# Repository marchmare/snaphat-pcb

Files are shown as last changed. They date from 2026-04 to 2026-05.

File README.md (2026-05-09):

# 🌻 SnapHAT - PCB design

<p align="center">
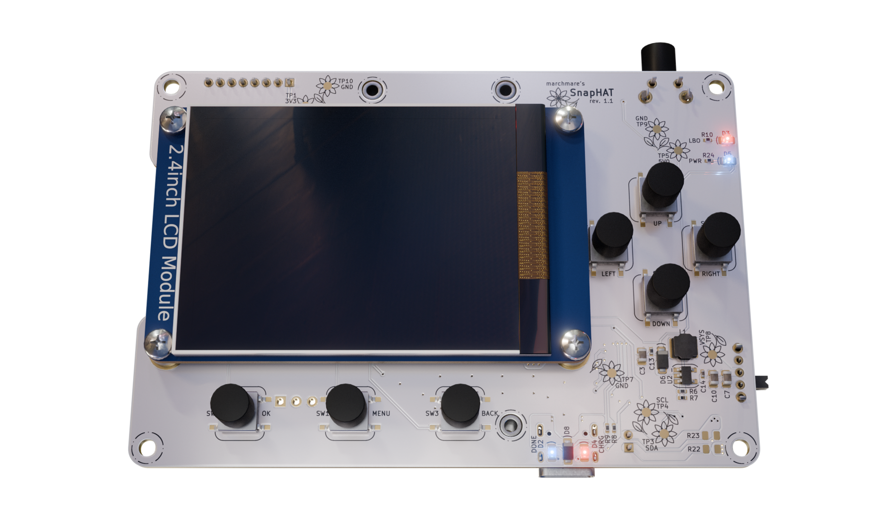
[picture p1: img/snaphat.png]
    
</p>

SnapHAT is an addon for RaspberryPi Zero 2 W serving as a handheld photo camera device.

This repository contains KiCad 9 design files for the PCBs of the SnapHAT device (rev.1.1).
The boards' layout is prepared to be compatible with JLCPCB standard 2-layer PCB quote.

> [!WARNING] 
> This repository is work in progress — core features are functional, but the PCB for this device is still evolving and some parts of the design are not yet behaving as I hoped.
> To avoid unnecessary hardware headaches, check [Troubleshooting and required reworks](#troubleshooting-and-required-reworks) section!

> [!TIP] 
> Python-based app for this camera can be found in **[this repository](https://github.com/marchmare/snaphat-sw)**.

### Table of contents:

* [Features](#features)
* [Repository structure](#repository-structure)
* [Bill of Materials](#bill-of-materials)
* [Wire harnesses](#wire-harnesses)
* [RaspberryPi header connection map](#raspberrypi-header-connection-map)
* [Troubleshooting and required reworks](#troubleshooting-and-required-reworks)

## Features

* 40-pin Raspberry Pi GPIO header for integration with RaspberryPi Zero 2 W
* 8-pin PH connector and mounting support for 320x240 Waveshare 18366 2.4" LCD TFT display
* Usable with ZeroCam OV5647 5MPx wide-angled 120° camera modules or same form-factor alternatives
* <del>1200mAh Li-Po battery support (30x40mm cell footprint, 2 pin PH connector), on-board battery charging (MCP73871) and power monitoring (INA219)</del>
* USB-C charging and OTG connector for RaspberryPi SD card access (USB 2.0)
* USB OTG pogo-pin breakout board as Raspberry Pi HAT, accessing USB singals through pogo-pins, connected to main board via 4pin FFC cable
* 8 tactile user interface buttons (navigation and shutter)
* LIS2DW12 motion sensor for providing image orientation metadata
* passive buzzer for audio feedback
* exposed debug UART pins
* flower testpads, because joy and whimsy is in demand

<p align="center">
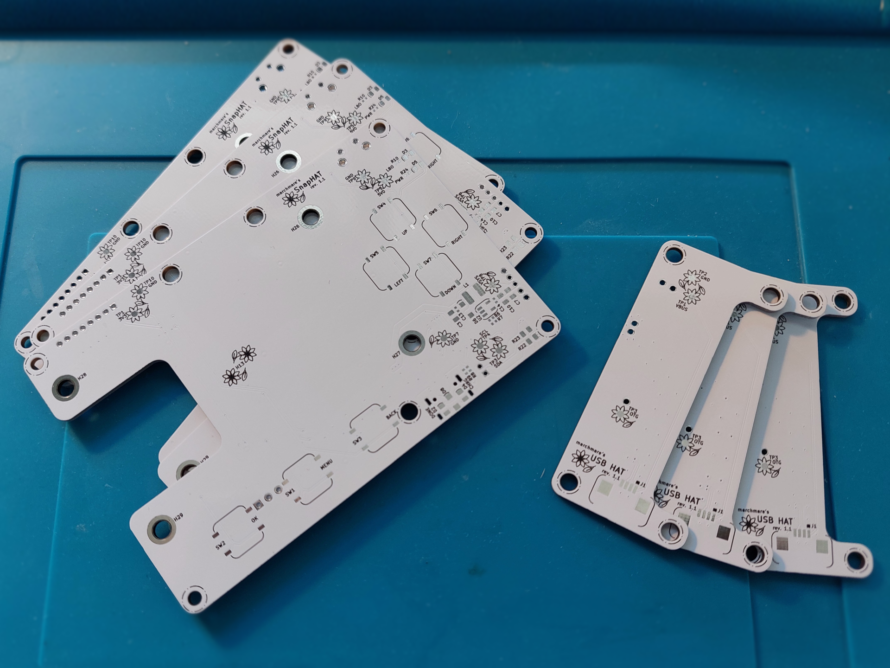
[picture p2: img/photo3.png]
    
</p>

## Repository structure

```
.
├─ main_board/
│   ├─ docs/
│   ├─ *.kicad_pro, *.kicad_sch, *.kicad_pcb
│   └─ README.md
├─ usb_hat/
│   ├─ docs/
│   ├─ *.kicad_pro, *.kicad_sch, *.kicad_pcb
│   └─ README.md
├─ img/
└─README.md
```

This repository contains two KiCad projects for each board:

* [**main_board**](main_board/) - SnapHAT main board with RaspberryPi socket connector and all camera device peripherals
* [**USB HAT**](usb_hat/) - USB OTG pogo-pin breakout board

Each board directory contains:

* `*.kicad_pro`, `*.kicad_sch`, `*.kicad_pcb` - KiCad 9 design files
* `docs/` - documentation outputs generated from the KiCad files - you will find BOM in CSV format and schematic PDF in there

In the root directory:
* `img/` - rendered previews of the boards and other images used by READMEs

## Bill of Materials

You can find BOMs for each board as CSV file in their respective `docs/` directories.
BOMs list PCB components, wire harness components, fasteners as well as OTS modules required to assemble the whole device. 

While designing SnapHAT, Farnell and TME were mostly taken into consideration as part vendors, however some parts need to be sourced from elsewhere (this applies mostly to OTS modules). 

Estimated component cost of the whole device is approximately 114 USD.

## Wire harnesses

<p align="center">
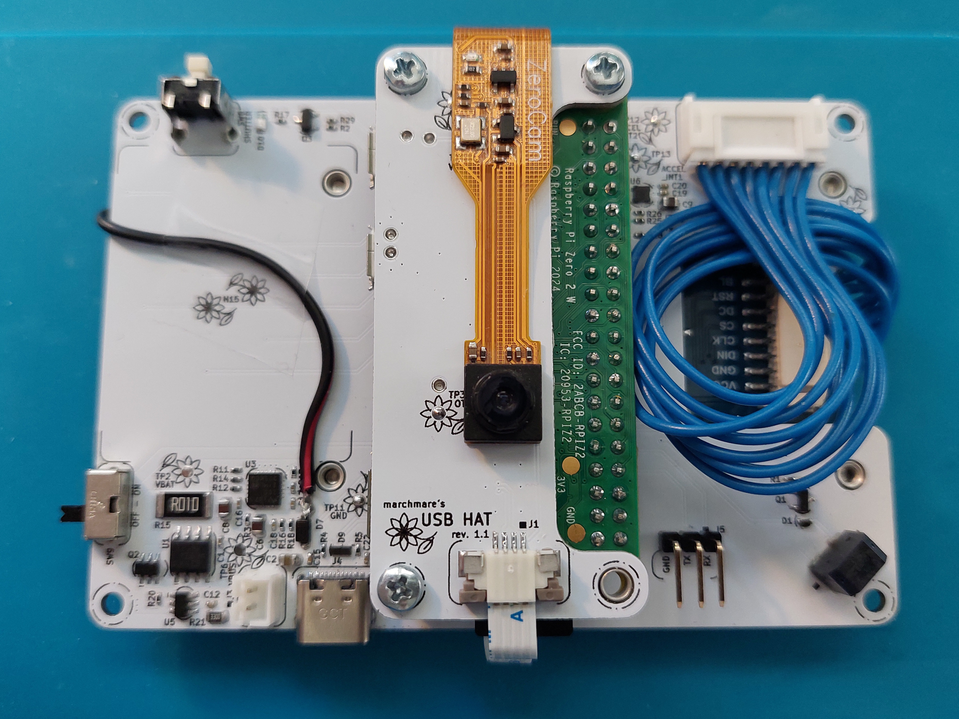
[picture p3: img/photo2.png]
    
</p>

### Display wire harness

To connect the Waveshare 18366 2.4" LCD TFT Display, use an 8-pin JST-PH (2.0 mm pitch) wire harness.
**This is not a straight-through cable — pin numbering is reversed between connectors.**

Part numbers for building the harness are listed in the main board's BOM and appear in its KiCad schematics as well.

#### Pin mapping:

| SnapHAT J1 | Signal | LCD PH connector |
|---|---|---|
| 1 | `3V3 (VCC)` | 8 |
| 2 | `GND` | 7 |
| 3 | `MOSI (DIN)`| 6 |
| 4 | `SCLK (CLK)`| 5 |
| 5 | `SPI_CS` | 4 |
| 6 | `DC` | 3 |
| 7 | `RST` | 2 |
| 8 | `BL` | 1 |

### USB HAT FFC cable

To connect SnapHAT's USB HAT, use 4 core (1.0 mm pitch) >50 mm FFC cable, with **opposite sided contacts**. Proposed part number for this cable is listed in the USB HAT's BOM and appear in its KiCad schematics as well.

SnapHAT and USB HAT both include FFC connectors with top-side contacts (SnapHAT: J6, USB HAT: J1). When plugged in, FFC stiffener should face the PCB on both ends.

#### Pin mapping:

| SnapHAT J6 | Signal | USB HAT J1 |
|---|---|---|
| 1 | `VBUS` | 1 |
| 2 | `USBC_DATA_N` | 2 |
| 3 | `USBC_DATA_P` | 3 |
| 4 | `GND` | 4 |

## RaspberryPi header connection map

Below table describes connected RaspberryPi GPIO pins and their intended function.

| Pin function | Signal name | GPIO (BCM) | Pin | Pin | GPIO (BCM) | Signal name | Pin function | 
| --- | --- | --- | --- | --- | --- | --- | --- |
| 3.3V power rail | `+3V3` | - | **1**  | **2**  | - | `+5V0` | 5V power rail |
| I2C data | `I2C_SDA` | 2 | **3**  | **4**  | - | `+5V0` | 5V power rail |
| I2C clock | `I2C_SCL` | 3 | **5**  | **6**  | - | `GND` | Ground |
| _Not connected_ | - | 4 | **7**  | **8**  | 14 | `RPI_UART_TX` | Debug UART Transmit |
| Ground | `GND` | - | **9**  | **10** | 15 | `RPI_UART_RX` | Debug UART Receive |
| Menu button | `BTN_MENU` | 17 | **11** | **12** | 18 | `BUZZER_SIGNAL`  | Buzzer PWM |
| A button | `BTN_A` | 27 | **13** | **14** | - | `GND` | Ground |
| B button | `BTN_B` | 22 | **15** | **16** | 23 | - | _Not connected_ |
| 3.3V power rail | `+3V3` | - | **17** | **18** | 24 | `DISPLAY_RST` | Display reset |
| Display SPI MOSI | `DISPLAY_MOSI` | 10 | **19** | **20** | - | `GND` | Ground |
| _Not connected_ | - | 9 | **21** | **22** | 25 | `DISPLAY_DC` | Display Data/Command |
| Display SPI serial clock  | `DISPLAY_SPI_SCLK` | 11 | **23** | **24** | 8 | `DISPLAY_SPI_CS` | Display SPI chip select |
| Ground | `GND` | - | **25** | **26** | 7 | - | _Not connected_ |
| Down button | `BTN_D` | 0 | **27** | **28** | 1 | - | _Not connected_ |
| Left button | `BTN_L` | 5 | **29** | **30** | - | `GND` | Ground |
| Right button | `BTN_R` | 6 | **31** | **32** | 12 | `DISPLAY_BL` | Display backlight PWM |
| Up button | `BTN_U` | 13 | **33** | **34** | - | `GND` | Ground |
| Low battery indicator LED | `LED_LBO` | 19 | **35** | **36** | 16 | `LED_SHUTTER` | Shutter activity LED indicator |
| Shutter button | `BTN_SHUTTER` | 26 | **37** | **38** | 20 | `ACCEL_INT1` | Motion sensor interrupt 1 |
| Ground | `GND` | - | **39** | **40** | 21 | `ACCEL_INT2` | Motion sensor interrupt 2 |

## Troubleshooting and required reworks

This revision's battery circuit (protection, charger and 5V boost) is still botched. Aside from this, SnapHAT is operational if powered by an external stable 5V supply like PC USB port or powerbank.

To make SnapHAT work in this case, simply connect VBUS to 5V0 (you can solder a wire between corresponding testpads). Keep the SW9 switch off to disable the battery charger circuit and prevent charging indicators flickering.

If you wish to dwell deeper into what's currently wrong with this design, here are symptoms observed during bringup:

* no power sourced from battery:
    - battery protection dual MOSFET have wrong topology, skip populating battery protection components entirely and populate R22 and R23 0R resistors instead to connect battery directly to the rest of the circuit. Make sure you use battery with a PCM in this case! 
* RaspberryPi stuck in boot loop when powering from battery or weaker USB port:
    - battery charging/boost regulator circuit is still wrong in this iteration, for the time being, connect VBUS testpad with the 5V0 one
* SnapHAT gets powered from connected USB-C connector when USB HAT is installed, despite turning SW9 in off position:
    - cut the VBUS trace going to J6 pin 1

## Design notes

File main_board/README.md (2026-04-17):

# SnapHAT main board

This directory contains design files and documentation for SnapHAT main board.

## Directory structure

```
.
└─ main_board/
   ├─ docs/
   │    ├─ *_bom.csv
   │    └─ *_schematic.pdf
   ├─ *.kicad_pro, *.kicad_sch, *.kicad_pcb
   └─ README.md
```

## Board previews

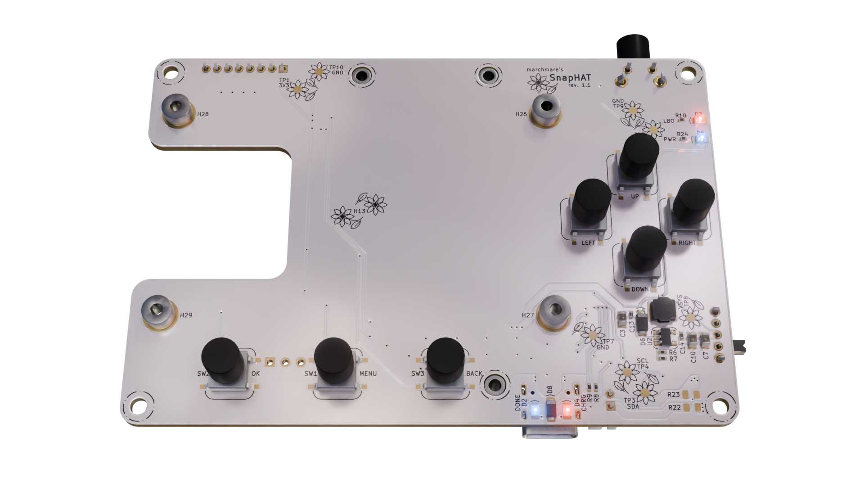
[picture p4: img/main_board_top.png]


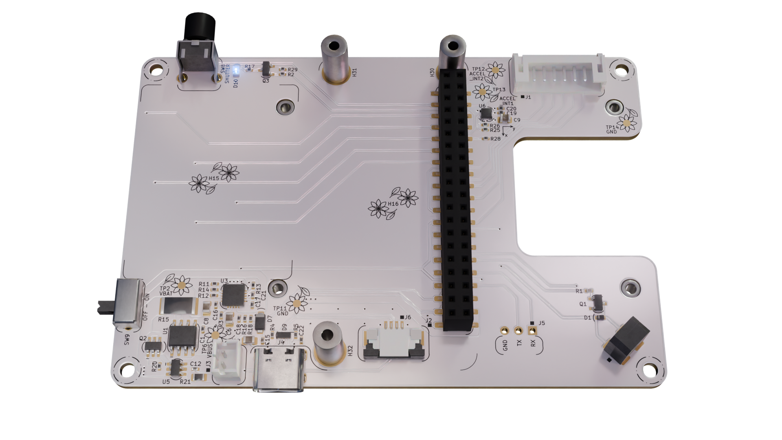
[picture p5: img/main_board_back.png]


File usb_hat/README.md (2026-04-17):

# SnapHAT USB HAT

This directory contains design files and documentation for SnapHAT USB HAT.

## Directory structure

```
.
└─ usb_hat/
   ├─ docs/
   │    ├─ *_bom.csv
   │    └─ *_schematic.pdf
   ├─ *.kicad_pro, *.kicad_sch, *.kicad_pcb
   └─ README.md
```

## Board previews

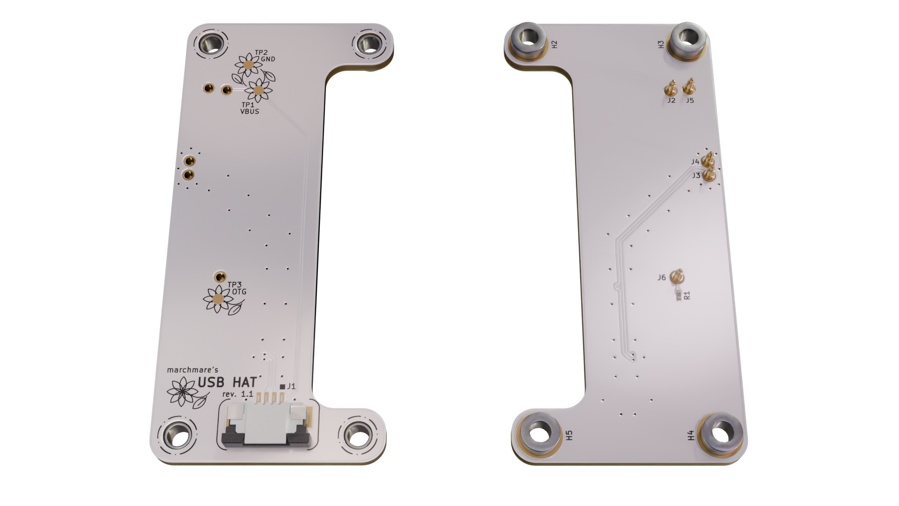
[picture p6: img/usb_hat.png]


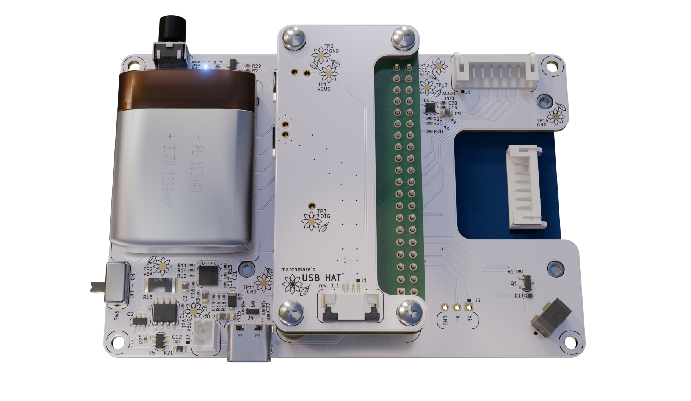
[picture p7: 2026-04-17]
img/snaphat_back.png

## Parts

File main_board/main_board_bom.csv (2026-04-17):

Reference | Qty | Value | Manufacturer | Part number | SKU | Category
BZ1 | 1 | KSSGL4B12-S | Kingstate | KSSGL4B12-S
C1,C12,C13,C14,C15,C16,C17,C18,C19,C20,C21,C22 | 12 | 100n | YAGEO | CS0402KRX7R7BB104
C2 | 1 | 22u | YAGEO | CC0805KKX5R5BB226
C3 | 1 | 2u2 | YAGEO | CC0805KKX7R6BB225
C6,C9,C10 | 3 | 10u | YAGEO | CC0805KFX7R6BB106
C7,C8 | 2 | 4u7 | YAGEO | CC0805KFX7R7BB475
D1 | 1 | 1N4148WT | ONSEMI | 1N4148WT
D2,D5,D10 | 3 | 0805 B LED | MULTICOMP PRO | MP008292
D3,D4 | 2 | 0805 R LED | MULTICOMP PRO | MP008293
D6,D7 | 2 | SL04-E3-08 | Vishay | SL04-E3-08
D8 | 1 | D_SMBJ5.0A | Littelfuse | SMBJ5.0A
D9 | 1 | SP1004U-ULC-04UTG | Littelfuse | SP1004U-ULC-04UTG
H1,H2,H3,H4,H5,H6,H7,H8 | 8 | B32-2010 | OMRON | B32-2010
H26,H27,H28,H29 | 4 | 9774030151R | Würth Elektronik | 9774030151R
H30,H31,H32 | 3 | 9774100151R | Würth Elektronik | 9774100151R
J1 | 1 | Conn_01x08_S8B-PH-K-S(LF)(SN) | JST | S8B-PH-K-S(LF)(SN)
J2 | 1 | Conn_02x20_2214SM-40G-75-PCR | MULTICOMP PRO | 2214SM-40G-75-PCR
J3 | 1 | Conn_01x02_B2B-PH-K-S(LF)(SN) | JST | B2B-PH-K-S(LF)(SN)
J4 | 1 | USB_C_USB4930-00-A | GCT | USB4930-00-A
J5 | 1 | Conn_01x03_MC34747 | MULTICOMP PRO | MC34747
J6 | 1 | Conn_01x04_FFC3B11-04-T | GCT | FFC3B11-04-T
L1 | 1 | L_LQH44PH100MPRL | Murata | LQH44PH100MPRL
Q1,Q3 | 2 | Q_BC817-25 | MULTICOMP PRO | BC817-25
Q2 | 1 | Q_FDC6561AN | ON Semiconductor | FDC6561AN
R1,R2,R12 | 3 | 1k | YAGEO | RC0402FR-071KL
R3,R11,R13,R16,R18,R25,R26 | 7 | 10k | YAGEO | RC0402FR-0710KL
R4,R5 | 2 | 5k1 | YAGEO | RC0402FR-075K1L
R6 | 1 | 100k | YAGEO | RC0402FR-07100KL
R7 | 1 | 33k | YAGEO | RC0402FR-0733KL
R8,R9,R17,R24 | 4 | 100R | YAGEO | RC0402JR-07100RL
R10 | 1 | 47R | YAGEO | RC0402JR-0747RL
R14,R20 | 2 | 2k7 | YAGEO | RC0402FR-072K7L
R15 | 1 | 0R01 | YAGEO | RL2512FK-070R01L
R21 | 1 | 330R | YAGEO | RC0805FR-07330RL
R22,R23 | 2 | 0R | YAGEO | RC0805JR-070RL
R28,R29 | 2 | 330R | YAGEO | RC0402FR-07330RL
SW1,SW2,SW3,SW4,SW5,SW6,SW7 | 7 | SW_B3FS-1050 | OMRON | B3FS-1050
SW8 | 1 | SW_B3F-3150 | OMRON | B3F-3150
SW9 | 1 | 1825232-1 | TE Connectivity | 1825232-1
U1 | 1 | INA219BIDR | Texas Instruments | INA219BIDR
U2 | 1 | MIC2250-1YD5-TR | Microchip Technology | MIC2250-1YD5-TR
U3 | 1 | MCP73871T-2CCI/ML | Microchip Technology | MCP73871T-2CCI/ML
U5 | 1 | AP9101CAK6-ABTRG1 | Diodes Inc. | AP9101CAK6-ABTRG1
U6 | 1 | LIS2DW12TR | STMicroelectronics | LIS2DW12TR
H9,H10,H11,H12 | 4 | 1386735 | BOSSARD | 1386735 |  | Fasteners
H34,H35,H36,H37 | 4 | M2.5x4 | BOSSARD | 1250396 |  | Fasteners
H40,H41,H42,H43 | 4 | M2.5x8 | BOSSARD | 1250434 |  | Fasteners
H44,H45,H46,H47 | 4 | M2.5x12 | BOSSARD | 1538543 |  | Fasteners
H53 | 1 | M2.5 nut | BOSSARD | 1088254 |  | Fasteners
H13 | 1 | 18366 | Waveshare | 18366 |  | OTS
H14 | 1 | ODS105 | Odseven | ODS105 |  | OTS
H15 | 1 | 10304 |  | 10304 |  | OTS
H16 | 1 | Raspberry Pi Zero 2 W | Raspberry Pi | SC1176 |  | OTS
H17,H18 | 2 | PHR-8 | JST | PHR-8 |  | Wire harness
H19,H20,H21,H22,H23,H24,H25,H52 | 8 | 01SPHSPH-26L-150 | JST | 01SPHSPH-26L-150 |  | Wire harness
H48,H49 | 2 | SPH-002T-P0.5S | JST | SPH-002T-P0.5S |  | Wire harness
H50 | 1 | PHR-2 | JST | PHR-2 |  | Wire harness

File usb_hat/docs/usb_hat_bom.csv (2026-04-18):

Reference | Qty | Value | Manufacturer | Part number | SKU | Category
H2,H3,H4,H5 | 4 | 9774020951R | Würth Elektronik | 9774020951R
J1 | 1 | Conn_01x04_FFC3B11-04-T | GCT | FFC3B11-04-T
J2,J3,J4,J5,J6 | 5 | P70-6000045R | Harwin | P70-6000045R
R1 | 1 | 0R | YAGEO | RC0402JR-070RL
H1 | 1 | 10-04-D-0050-C-4-08-4-T | GCT | 10-04-D-0050-C-4-08-4-T |  | Wire harness

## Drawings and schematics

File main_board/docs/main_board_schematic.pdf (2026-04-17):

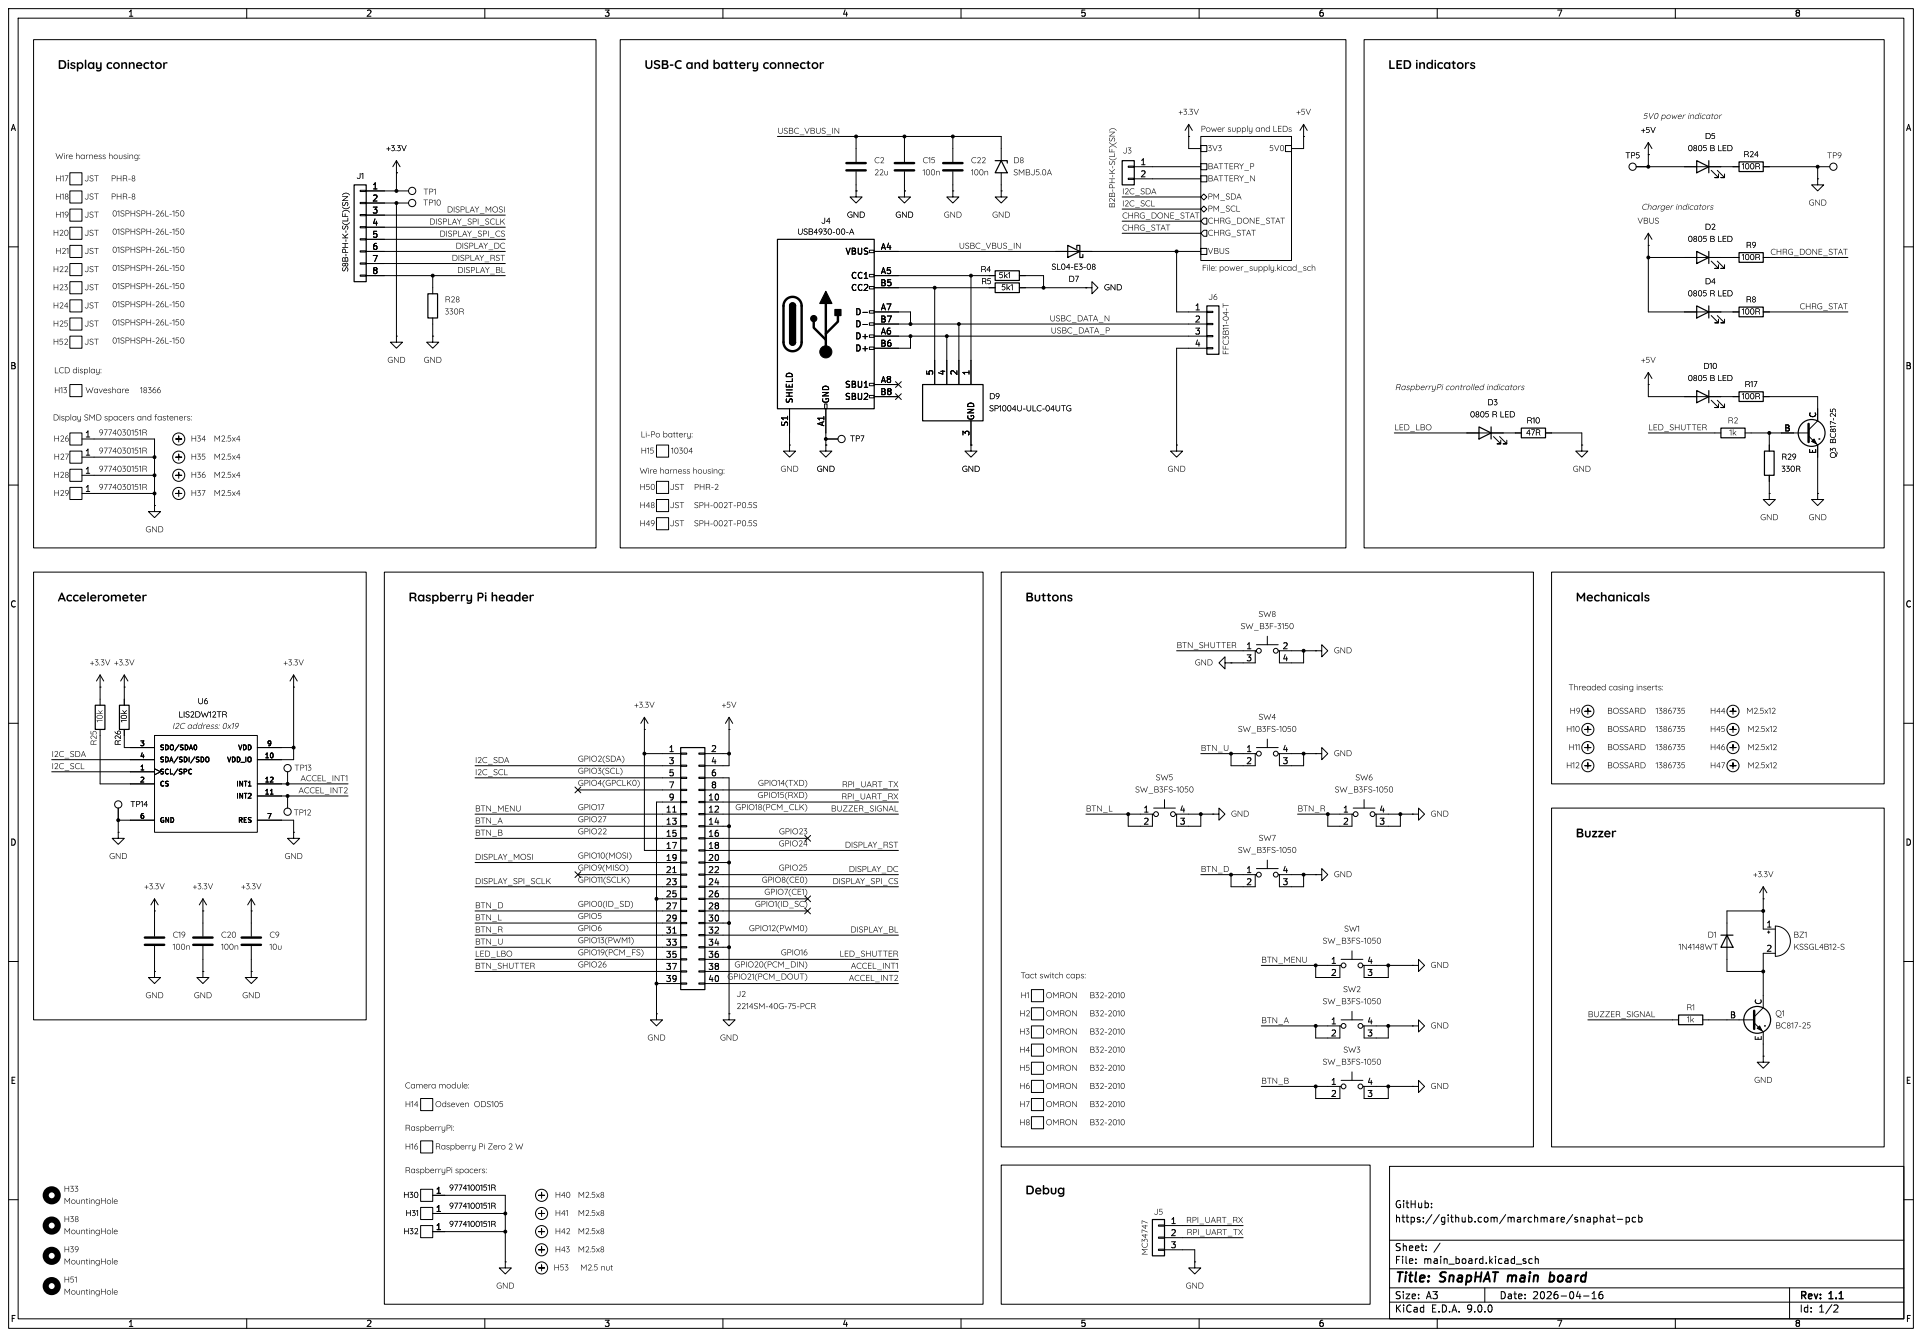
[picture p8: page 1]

Wire harness housing: LCD display:

USB-Cand battery connector

5V0 power indicator Charger indicators Buttons Wire harness housing: Li-Po battery:

VBUS CHRG_DONE_STAT CHRG_STAT Power supply and LEDs File:power_supply.kicad_sch

File: main_board.kicad_sch Sheet: / https://github.com/marchmare/snaphat-pcb GitHub:

Id: 1/2 Title: SnapHAT main board

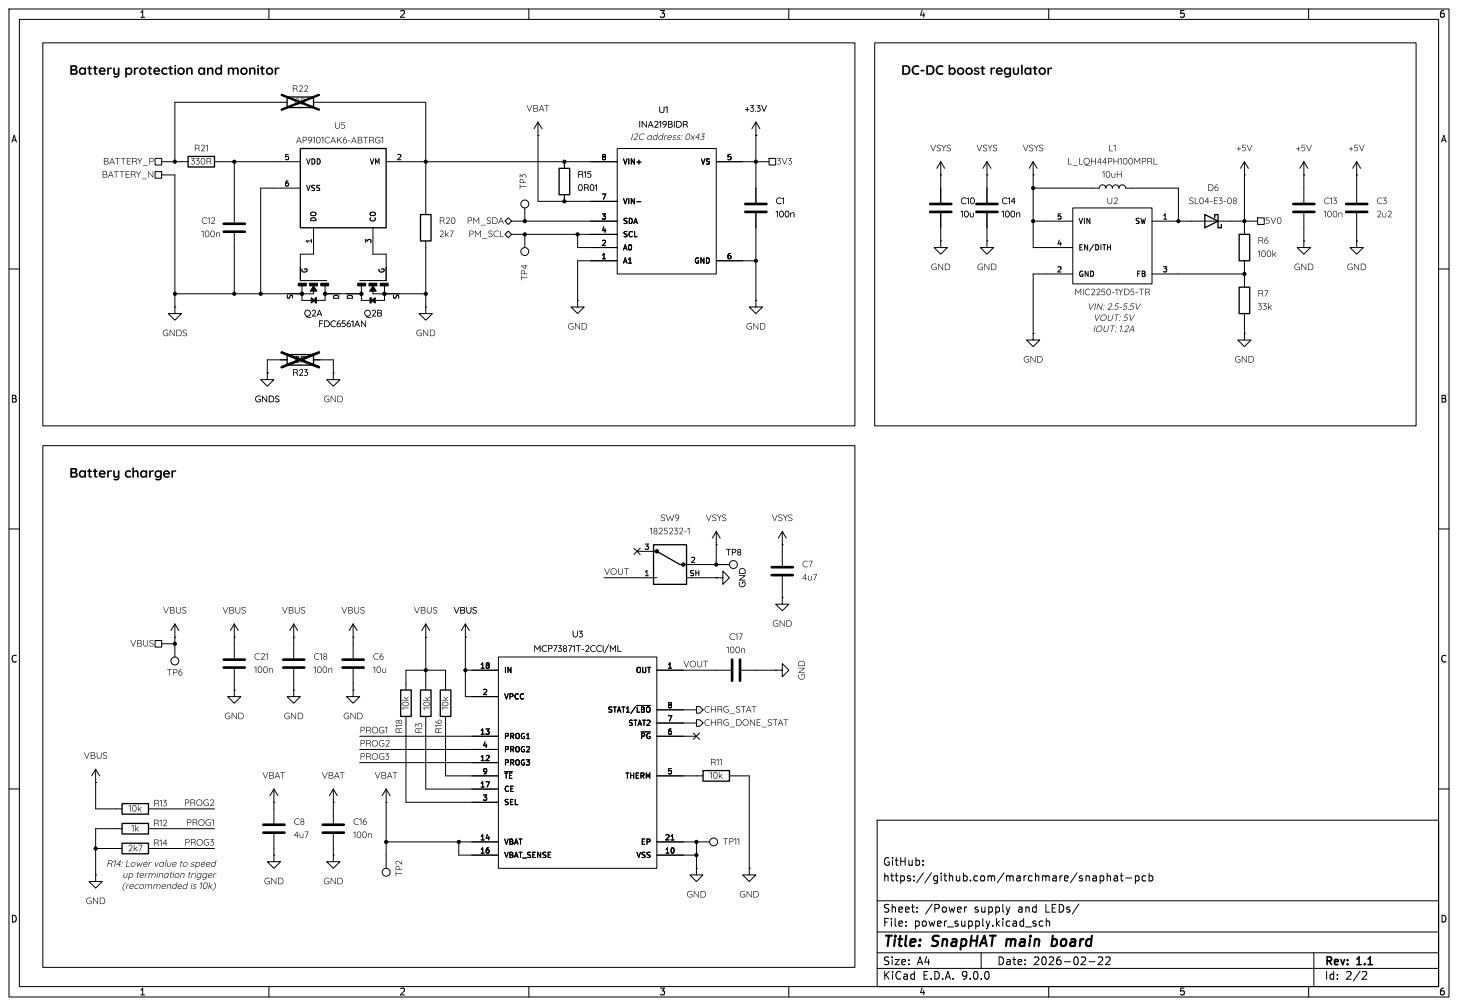
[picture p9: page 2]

IOUT:1.2A DC-DC boost regulator

R14:Lower value to speed
up termination trigger
(recommended is 10k)

Id: 2/2 Title: SnapHAT main board

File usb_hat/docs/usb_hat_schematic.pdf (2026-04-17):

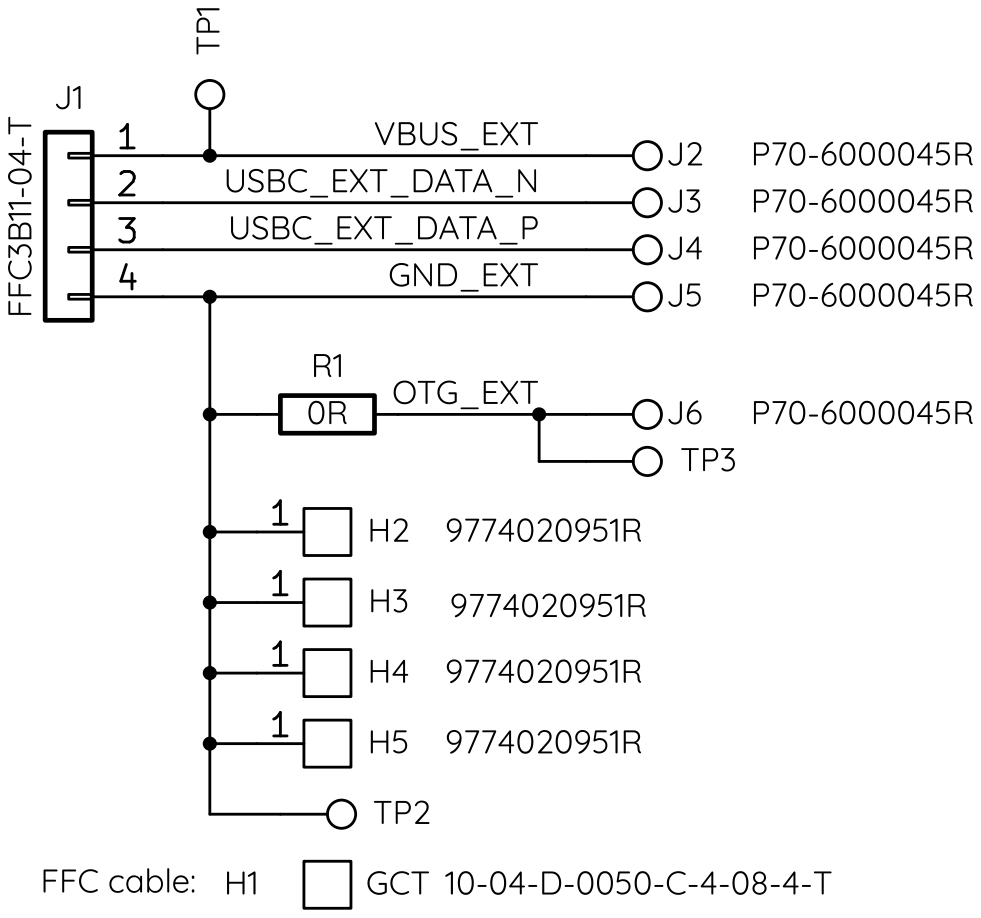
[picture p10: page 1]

File: usb_hat.kicad_sch Sheet: / https://github.com/marchmare/snaphat-pcb GitHub:

Id: 1/1 Title: USB HAT

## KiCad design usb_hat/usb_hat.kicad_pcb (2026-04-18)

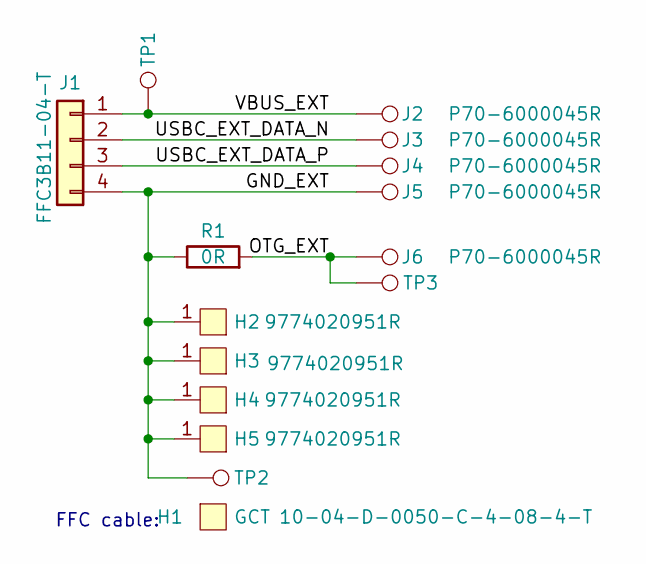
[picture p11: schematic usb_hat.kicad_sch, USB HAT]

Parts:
H1: 10-04-D-0050-C-4-08-4-T; Part number 10-04-D-0050-C-4-08-4-T
H2, H3, H4, H5: 9774020951R; Mounting_Wuerth_WA-SMST-2.7mm_H2mm_9774020951; Part number 9774020951R
J1: Conn_01x04_FFC3B11-04-T; GCT_FFC3B11-04-T; Part number FFC3B11-04-T
J2, J3, J4, J5, J6: P70-6000045R; HARWIN_P70-6000045R; Part number P70-6000045R
R1: 0R; R_0402_1005Metric; Part number RC0402JR-070RL
TP1, TP2, TP3: TestPoint; TestPoint_Pad_D1.5mm

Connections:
/GND_EXT: H2.1, H3.1, H4.1, H5.1, J1.4, J5.1, R1.1, TP2.1
/OTG_EXT: J6.1, R1.2, TP3.1
/USBC_EXT_DATA_N: J1.2, J3.1
/USBC_EXT_DATA_P: J1.3, J4.1
/VBUS_EXT: J1.1, J2.1, TP1.1

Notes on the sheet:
FFC cable:

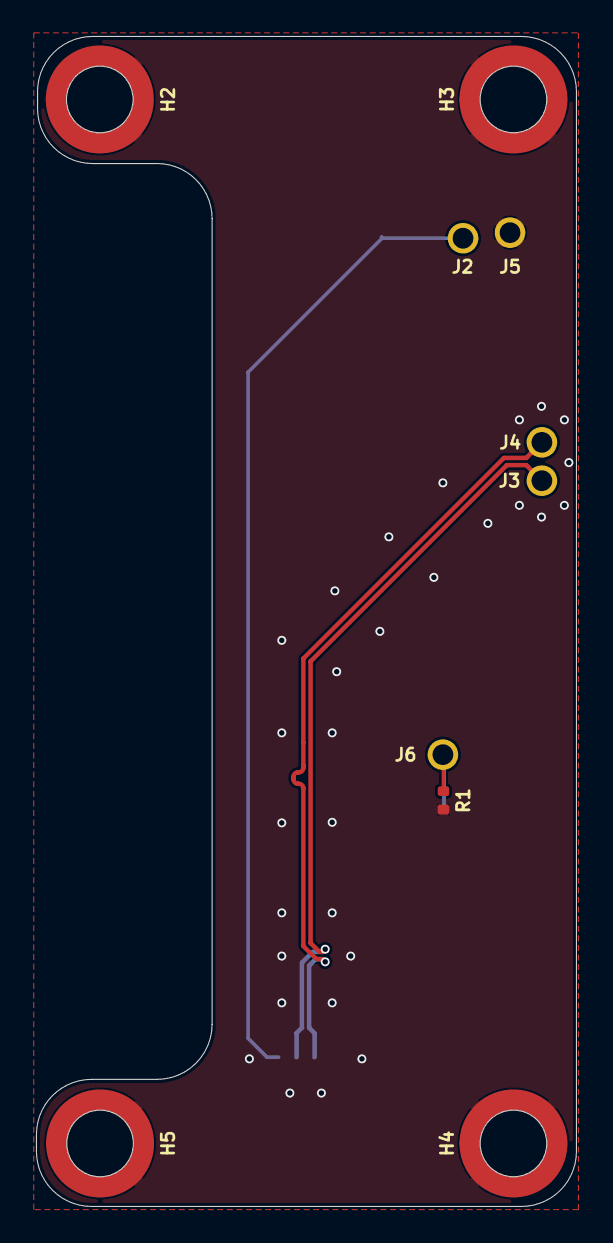
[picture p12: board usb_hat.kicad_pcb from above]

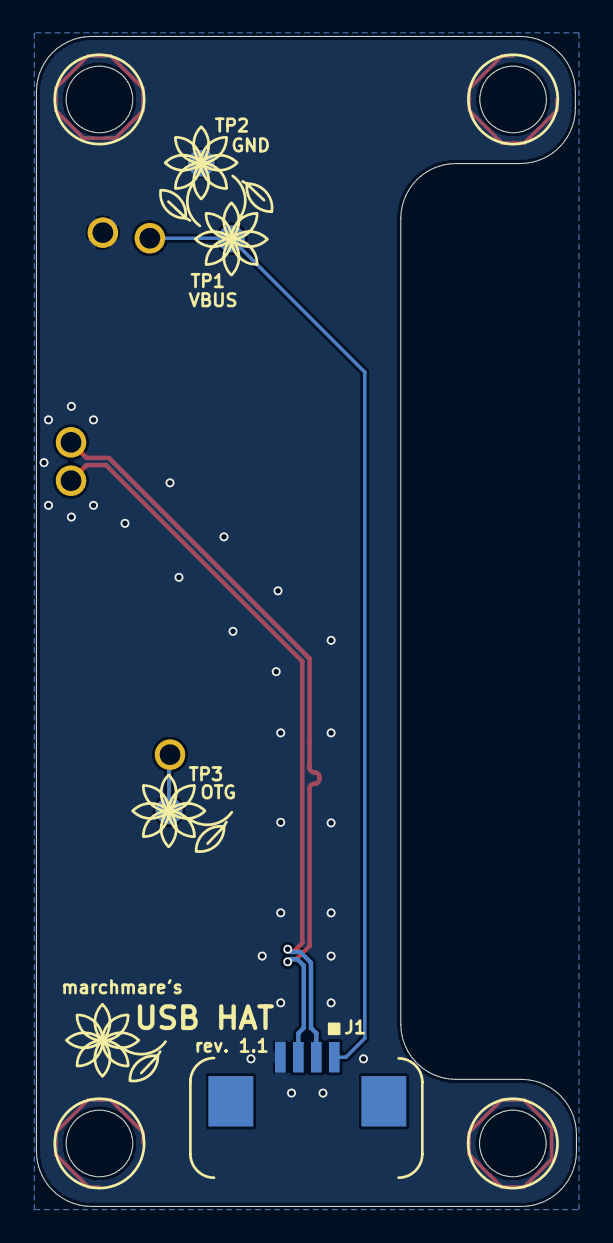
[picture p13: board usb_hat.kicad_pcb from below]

Board: 2 copper layers, 30.0 x 65.0 mm, 14 parts (4 on the bottom side), 5 nets.

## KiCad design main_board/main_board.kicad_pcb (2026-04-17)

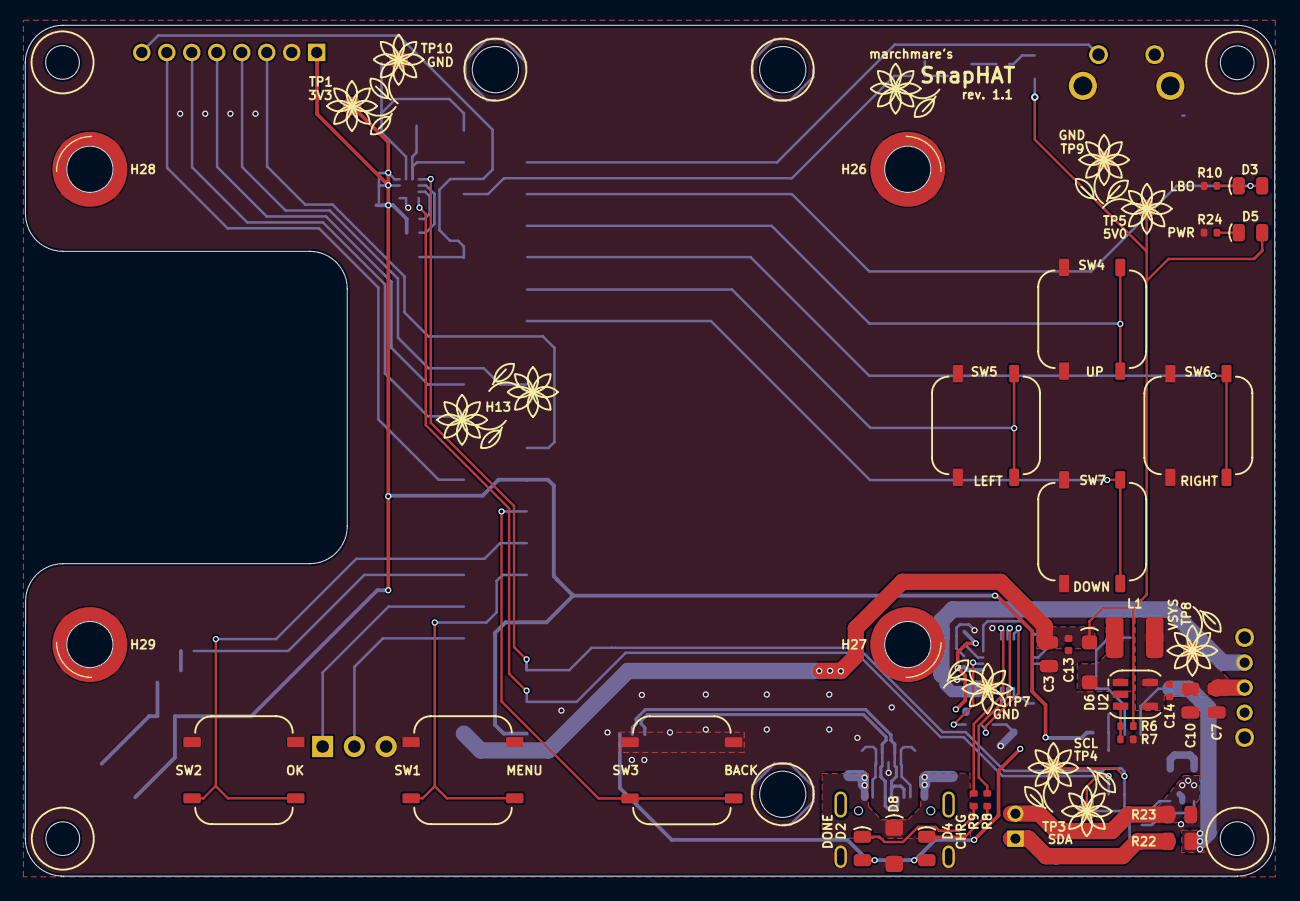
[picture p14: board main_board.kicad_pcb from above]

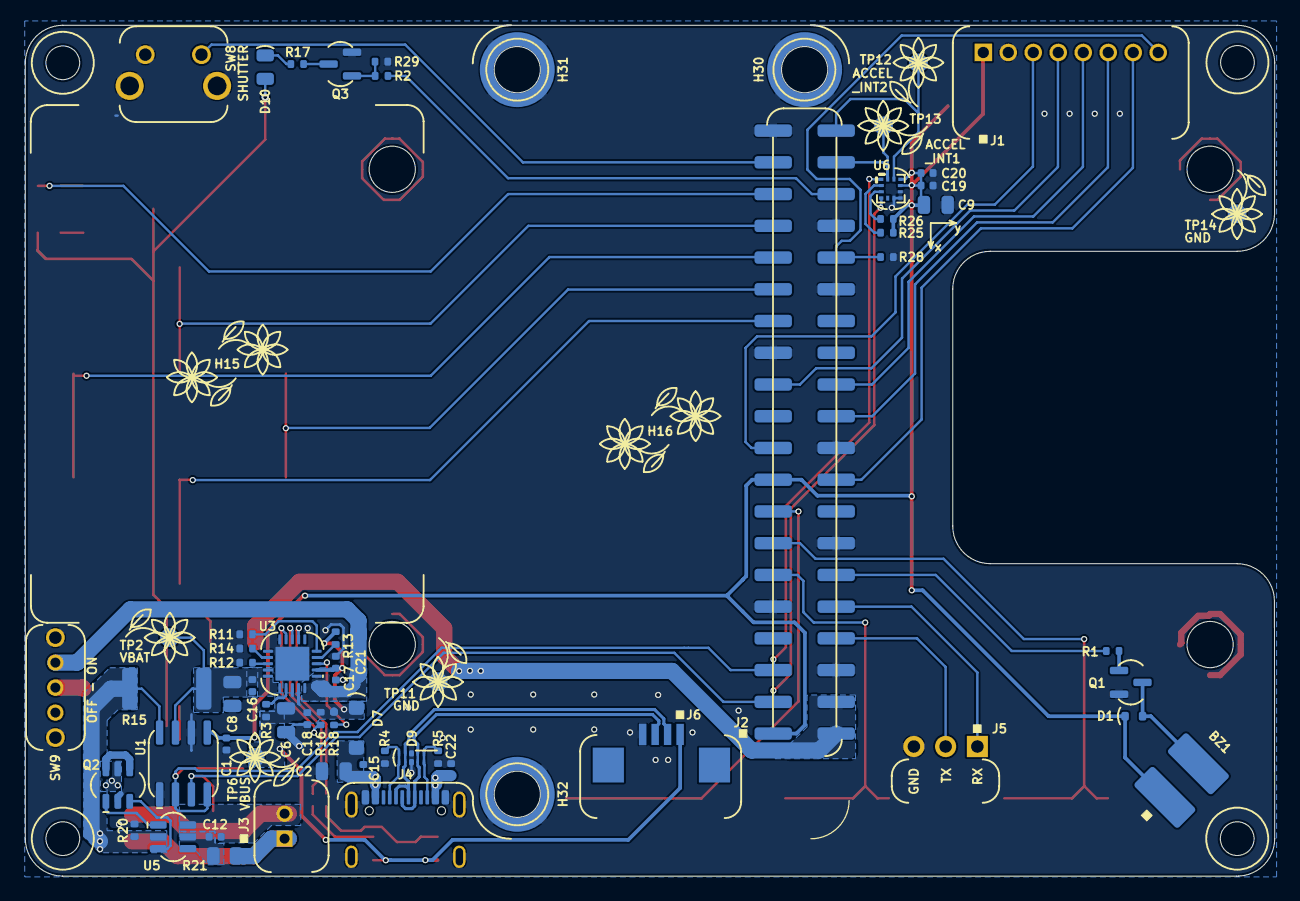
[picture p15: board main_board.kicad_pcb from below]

Board: 2 copper layers, 100.0 x 68.1 mm, 109 parts (64 on the bottom side), 64 nets.

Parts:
BZ1: KSSGL4B12-S; XDCR_KSSGL4B12-S
C1, C12, C13, C14, C15, C16, C17, C18, C19, C20, C21, C22: 100n; C_0402_1005Metric
C2: 22u; C_0805_2012Metric
C3: 2u2; C_0805_2012Metric
C6, C9, C10: 10u; C_0805_2012Metric
C7, C8: 4u7; C_0805_2012Metric
D1: 1N4148WT; D_SOD-523
D2, D5, D10: 0805 B LED; LED_0805_2012Metric
D3, D4: 0805 R LED; LED_0805_2012Metric
D6, D7: SL04-E3-08; DO-219AB
D8: D_SMBJ5.0A; SOD-123FL
D9: SP1004U-ULC-04UTG; SP1004UULC04UTG
H13: 18366
H15: 10304; Li-Pol_battery_8x30x40mm
H16: Raspberry Pi Zero 2 W; Raspberry_Pi_Zero_Socketed_THT_FaceDown_MountingHoles
H26, H27, H28, H29: 9774030151R; Mounting_Wuerth_WA-SMSI-M2.5_H3mm_9774030151R
H30, H31, H32: 9774100151R; Mounting_Wuerth_WA-SMSI-M2.5_H10mm_9774100151R
H33, H38, H39, H51: MountingHole; MountingHole_2.7mm
J1: Conn_01x08_S8B-PH-K-S(LF)(SN); JST_S8B-PH-K-S_LF__SN_
J2: Conn_02x20_2214SM-40G-75-PCR; PinSocket_2x20_P2.54mm_Vertical_SMD
J3: Conn_01x02_B2B-PH-K-S(LF)(SN); JST_B2B-PH-K-S_LF__SN_
J4: USB_C_USB4930-00-A; USB_C_Receptacle_GCT_USB4105-xx-A_16P_TopMnt_Horizontal
J5: Conn_01x03_MC34747; PinHeader_1x03_P2.54mm_Horizontal
J6: Conn_01x04_FFC3B11-04-T; GCT_FFC3B11-04-T
L1: L_LQH44PH100MPRL; L_LPH44PH
Q1, Q3: Q_BC817-25; SOT-23
Q2: Q_FDC6561AN; SSOT-6
R1, R2, R12: 1k; R_0402_1005Metric
R3, R11, R13, R16, R18, R25, R26: 10k; R_0402_1005Metric
R4, R5: 5k1; R_0402_1005Metric
R6: 100k; R_0402_1005Metric
R7: 33k; R_0402_1005Metric
R8, R9, R17, R24: 100R; R_0402_1005Metric
R10: 47R; R_0402_1005Metric
R14, R20: 2k7; R_0402_1005Metric
R15: 0R01; R_2512_6332Metric
R21: 330R; R_0805_2012Metric
R22, R23: 0R; R_0805_2012Metric
R28, R29: 330R; R_0402_1005Metric
SW1, SW2, SW3, SW4, SW5, SW6, SW7: SW_B3FS-1050; SW_B3FS-105xx
SW8: SW_B3F-3150
SW9: 1825232-1
TP1, TP2, TP3, TP4, TP5, TP6, TP7, TP8, TP9, TP10, TP11, TP12, TP13, TP14: TestPoint; TestPoint_Pad_D1.5mm
U1: INA219BIDR; SOIC-8_3.9x4.9mm_P1.27mm
U2: MIC2250-1YD5-TR; TSOT-23-5
U3: MCP73871T-2CCI/ML; QFN-20-1EP_4x4mm_P0.5mm_EP2.7x2.7mm
U5: AP9101CAK6-ABTRG1; SOT-26
U6: LIS2DW12TR; LGA12R50P4X4_200X200X70

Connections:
+3.3V: BZ1.1 (+), C1.1, C9.1, C19.1, C20.1, D1.1 (K), J1.1, J2.1, J2.17, R25.2, R26.2, TP1.1, U1.5 (VS), U6.9 (VDD), U6.10 (VDD_IO)
+5V: C3.1, C13.2, D5.2 (A), D6.1 (K), D10.2 (A), J2.2, J2.4, R6.1, TP5.1
/ACCEL_INT1: J2.38, TP13.1, U6.12 (INT1)
/ACCEL_INT2: J2.40, TP12.1, U6.11 (INT2)
/BTN_A: J2.13, SW2.1, SW2.2
/BTN_B: J2.15, SW3.1, SW3.2
/BTN_D: J2.27, SW7.1, SW7.2
/BTN_L: J2.29, SW5.1, SW5.2
/BTN_MENU: J2.11, SW1.1, SW1.2
/BTN_R: J2.31, SW6.1, SW6.2
/BTN_SHUTTER: J2.37, SW8.1
/BTN_U: J2.33, SW4.1, SW4.2
/BUZZER_SIGNAL: J2.12, R1.1
/CHRG_DONE_STAT: R9.1, U3.7 (STAT2)
/CHRG_STAT: R8.1, U3.8 (STAT1/~LBO)
/DISPLAY_BL: J1.8, J2.32, R28.1
/DISPLAY_DC: J1.6, J2.22
/DISPLAY_MOSI: J1.3, J2.19
/DISPLAY_RST: J1.7, J2.18
/DISPLAY_SPI_CS: J1.5, J2.24
/DISPLAY_SPI_SCLK: J1.4, J2.23
/I2C_SCL: J2.5, TP4.1, U1.2 (A0), U1.4 (SCL), U6.1 (SCL/SPC)
/I2C_SDA: J2.3, TP3.1, U1.3 (SDA), U6.4 (SDA/SDI/SDO)
/LED_LBO: D3.2 (A), J2.35
/LED_SHUTTER: J2.36, R2.1
/Power supply and LEDs/BATTERY_P: J3.1, R21.2, R22.1
/Power supply and LEDs/PROG1: R12.1, U3.13 (PROG1)
/Power supply and LEDs/PROG2: R13.1, U3.4 (PROG2)
/Power supply and LEDs/PROG3: R14.2, U3.12 (PROG3)
/Power supply and LEDs/VOUT: C17.2, SW9.1, U3.1 (OUT), U3.20 (OUT)
/RPI_UART_RX: J2.10, J5.1
/RPI_UART_TX: J2.8, J5.2
/USBC_DATA_N: D9.2, D9.9 (NC_3), J4.A7 (D-), J4.B7 (D-), J6.2
/USBC_DATA_P: D9.4, D9.7 (NC_2), J4.A6 (D+), J4.B6 (D+), J6.3
/USBC_VBUS_IN: C2.1, C15.2, C22.2, D7.2 (A), D8.1 (A1), J4.A4 (VBUS), J4.A9 (VBUS), J4.B4 (VBUS), J4.B9 (VBUS)
GND: C1.2, C2.2, C3.2, C6.2, C7.2, C8.2, C9.2, C10.2, C13.1, C14.1, C15.1, C16.1, C17.1, C18.1, C19.2, C20.2, C21.1, C22.1, D8.2 (A2), D9.3 (GND), D9.8 (GND_2), H26.1, H27.1, H28.1, H29.1, H30.1, H31.1, H32.1, J1.2, J2.6, J2.9, J2.14, J2.20, J2.25, J2.30, J2.34, J2.39, J4.A1 (GND), J4.A12 (GND), J4.B1 (GND), J4.B12 (GND), J4.S1 (SHIELD), J5.3, J6.4, Q1.2 (E), Q2.2, Q3.2 (E), R4.1, R5.1, R7.2, R10.1, R11.1, R12.2, R14.1, R20.1, R23.2, R24.1, R28.2, R29.2, SW1.3 (K), SW1.4 (A), SW2.3 (K), SW2.4 (A), SW3.3 (K), SW3.4 (A), SW4.3 (K), SW4.4 (A), SW5.3 (K), SW5.4 (A), SW6.3 (K), SW6.4 (A), SW7.3 (K), SW7.4 (A), SW8.2, SW8.3, SW8.4, SW9.SH, TP7.1, TP9.1, TP10.1, TP11.1, TP14.1, U1.1 (A1), U1.6 (GND), U2.2 (GND), U3.10 (VSS), U3.11 (VSS), U3.21 (EP), U6.6 (GND), U6.7 (RES), U6.8 (GND)
GNDS: C12.2, J3.2, Q2.5, R23.1, U5.6 (VSS)
unnamed: BZ1.2 (-), D1.2 (A), Q1.3 (C)
unnamed: D2.1 (K), R9.2
unnamed: D3.1 (K), R10.2
unnamed: D4.1 (K), R8.2
unnamed: D5.1 (K), R24.2
unnamed: D6.2 (A), L1.2, U2.1 (SW)
unnamed: D9.5, D9.6 (NC_1), J4.B5 (CC2), R5.2
unnamed: D9.1, D9.10 (NC_4), J4.A5 (CC1), R4.2
unnamed: D10.1 (K), R17.1
unnamed: Q1.1 (B), R1.2
unnamed: Q2.4, Q2.6
unnamed: Q3.1 (B), R2.2, R29.1
unnamed: Q3.3 (C), R17.2
unnamed: R15.1, R20.2, R22.2, U1.8 (VIN+), U5.2 (VM)
unnamed: R6.2, R7.1, U2.3 (FB)
unnamed: R3.2, U3.17 (CE)
unnamed: R18.2, U3.3 (SEL)
unnamed: R11.2, U3.5 (THERM)
unnamed: R16.1, U3.9 (~TE)
unnamed: Q2.3, U5.3 (CO)
unnamed: Q2.1, U5.1 (DO)
unnamed: C12.1, R21.1, U5.5 (VDD)
unnamed: R25.1, U6.2 (CS)
unnamed: R26.1, U6.3 (SDO/SDA0)
VBAT: C8.1, C16.2, R15.2, TP2.1, U1.7 (VIN-), U3.14 (VBAT), U3.15 (VBAT), U3.16 (VBAT_SENSE)
VBUS: C6.1, C18.2, C21.2, D2.2 (A), D4.2 (A), D7.1 (K), J6.1, R3.1, R13.2, R16.2, R18.1, TP6.1, U3.2 (VPCC), U3.18 (IN), U3.19 (IN)
VSYS: C7.1, C10.1, C14.2, L1.1, SW9.2, TP8.1, U2.4 (EN/DITH), U2.5 (VIN)

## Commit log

2026-03-19 Add design files, README, bom and schematic
    [snaphat.kicad_pcb, snaphat.kicad_sch, snaphat_bom.csv]
2026-03-19 Replace boost regulator with MIC2250-1YD5-TR
    [snaphat.kicad_sch]
2026-03-19 Add display backlight pulldown
    [snaphat.kicad_sch]
2026-03-19 Update slide switch reference to SW
    [snaphat.kicad_sch]
2026-03-19 Replace Q2 and Q3 with FDC6561AN
    [snaphat.kicad_sch]
2026-03-20 Add USB OTG
    [snaphat.kicad_sch]
2026-03-22 Move power supply block to separate sheet, bringup fixes
    [power_supply.kicad_sch, snaphat.kicad_sch]
2026-03-22 Fix BC817-25 symbol (wrong pinout)
    [snaphat.kicad_sch]
2026-03-22 Update spacers
    [snaphat.kicad_sch]
2026-03-22 Fix B3F-3150 symbol
    [snaphat.kicad_sch]
2026-03-22 Fixes to power charger, cleanup schematic
    [power_supply.kicad_sch, snaphat.kicad_sch]
2026-04-09 Start updating PCB, library fixes
    [power_supply.kicad_sch, snaphat.kicad_pcb, snaphat.kicad_sch]
2026-04-10 Rerouted power and USB
    [snaphat.kicad_pcb, snaphat.kicad_sch]
2026-04-11 Fix RPi connector on schematic, route rest of signals
    [snaphat.kicad_pcb, snaphat.kicad_sch]
2026-04-11 Layout nits, add proper mounting holes
    [snaphat.kicad_pcb, snaphat.kicad_sch]
2026-04-11 Zone fixes
    [snaphat.kicad_pcb]
2026-04-11 Fix initial DRC problems, add draft USB hat
    [snaphat.kicad_pcb]
2026-04-12 Route USB hat
    [snaphat.kicad_pcb]
2026-04-12 Layout nits
    [snaphat.kicad_pcb, snaphat.kicad_sch]
2026-04-12 Arrange designators, clear DRC, cleanups
    [power_supply.kicad_sch, snaphat.kicad_pcb, snaphat.kicad_sch]
2026-04-12 Add FFC cable info
    [snaphat.kicad_pcb, snaphat.kicad_sch]
2026-04-12 Fixes to library, add updated schematic PDF and BOM
    [power_supply.kicad_sch, snaphat.kicad_sch, snaphat_bom.csv]
2026-04-13 Add LED_SHUTTER
    [power_supply.kicad_sch, snaphat.kicad_pcb, snaphat.kicad_sch]
2026-04-13 Replace FFC connector with 1mm pitch
    [snaphat.kicad_pcb, snaphat.kicad_sch]
2026-04-14 Reroute USB, add shutter LED signal pulldown
    [power_supply.kicad_sch, snaphat.kicad_pcb, snaphat.kicad_sch]
2026-04-14 Update README and docs
    [snaphat.kicad_pcb, snaphat.kicad_sch, snaphat_bom.csv]
2026-04-16 Move main board to separate project
    [main_board.kicad_pcb, main_board.kicad_sch, main_board_bom.csv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]
2026-04-16 Move USB HAT to separate project
    [usb_hat.kicad_pcb, usb_hat.kicad_sch, usb_hat_bom.csv]
2026-04-16 Clear root dir
    [power_supply.kicad_sch, snaphat.kicad_pcb, snaphat.kicad_sch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]
2026-04-16 Fix differential pair clearence in board settings and GND pour
    [main_board.kicad_pcb, usb_hat.kicad_pcb]
2026-04-18 Fix P70-6000045R missing from BOM
    [usb_hat.kicad_pcb, usb_hat.kicad_sch, usb_hat_bom.csv]
2026-05-05 Add TODOs from rev.1.1 bringup
    [main_board.kicad_sch, power_supply.kicad_sch]
2026-05-06 Update README's troubleshooting section, update bringup TODOs
    [power_supply.kicad_sch]
2026-05-09 Update README (real life photos, wire harness info), add a TODO
    [main_board.kicad_sch]
